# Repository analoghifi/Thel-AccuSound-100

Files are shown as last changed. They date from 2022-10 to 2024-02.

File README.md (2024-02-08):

# Thel AccuSound 100
Thel AccuSound 100 audio power amplifier module (mono single channel)  
using vertical MOSFETs (often generalised as "[HEXFET](https://sound-au.com/articles/hexfet.htm)s")
* RMS power output from 20W up to 500W\* (1000W\*\*) | 7Hz...1,5MHz [-3dB]  |  0,4µs
* Class-A-Mode possible | Bridge Mode possible  
* unbalanced (single-ended/asymmetrical) audio input  
* not DC-coupled (has an input Cap (KP film/foil))  
* using vertical MOSFETs IRFP240 / IRFP9240  
* integrated (DC-) protection & anti-pop delay -circuit with relays
  
\*(depends on the supply voltage only)  
\*\*(bridge mode and short time only ➔ see <a href="/docs/4.) final version 2003-2015/power_output_table_version_2003-2015.png">Table 1</a> / <a href="/docs/3) version 1995-2003/power_output_table_version_1995-2003__V2.jpg">Table 2</a>)  
  
#### changes from "3) version 1995-2003" *[AccuSound Pro]* to "4) final version 2003-2015" *[AccuSound 100]*:  
* introducing source resistors (for better stability / better thermal behaviour / better currenct and load sharing)
* therefore reduced power output (compare <a href="/docs/3) version 1995-2003/power_output_table_version_1995-2003__V2.jpg">old</a> with <a href="/docs/4.) final version 2003-2015/power_output_table_version_2003-2015.png">new</a>)
* slightly different schematic (compare <a href="/hardware/3) version 1995-2003/accusound_version_1995-2003_schematic_V1.jpg">old</a> with <a href="/hardware/4.) final version 2003-2015/AccuSound_100_schematic_2004__corrected.jpg">new</a>)
* different pcb layout
* in the middle of 2010: replacement of the 2 very good tungsten-silver double (two-step)\*\*\* contact relays (erosion-resistant) with 2 normal "high-current" relays (Schrack RP3SL024)  
* replacing almost all foil caps (including the input cap) with the very good CDE film/foil KP-caps (<a href="https://github.com/analoghifi/capacitors/blob/main/audio%20and%20filter%20capacitors/docs/datasheets/kp/CDE_series_WPP.pdf">WPP-Series</a>)
* introducing silver mica bypass caps at some sensible places in the circuit
  
\*\*\*(see here -> <a href="/docs/components datasheets/special relay version 1995-2003">Relay type: Hengstler H-550-1759"</a>)
  
.
  
## last 4.x) version sold from 2003 til 2015:  
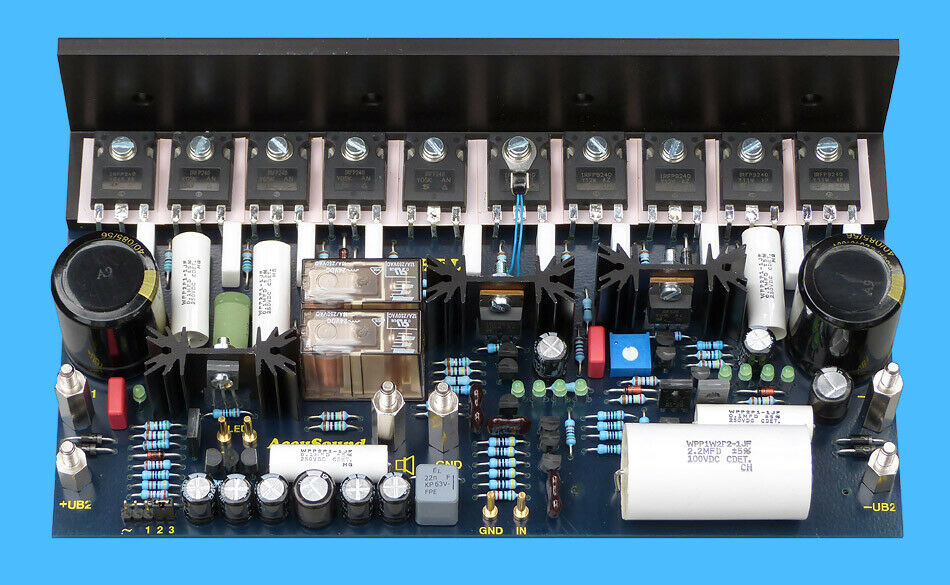
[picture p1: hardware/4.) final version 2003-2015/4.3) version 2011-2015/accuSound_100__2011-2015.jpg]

  
https://web.archive.org/web/20071014012558/http://www.thel-audioworld.de/module/acuso/acuso.htm  
https://web.archive.org/web/20120130132153/http://thel-audioworld.de/module/acuso/acuso.htm  
https://web.archive.org/web/20150216004915/http://www.thel-audioworld.de/module/acuso/acuso.htm  
  
## older 3) version sold from 1995 til 2003:  
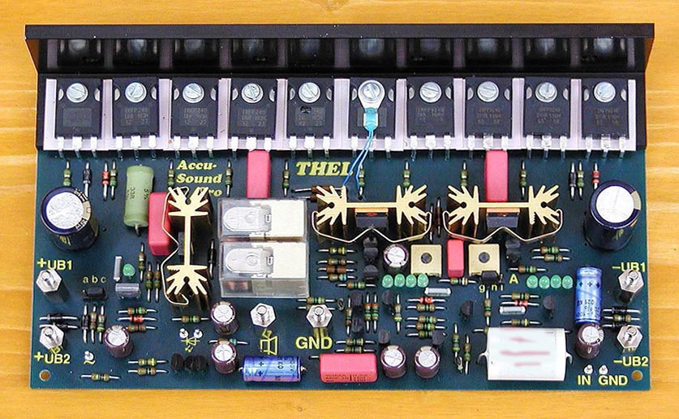
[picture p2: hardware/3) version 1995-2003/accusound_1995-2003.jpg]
  
  
https://web.archive.org/web/20020608091959/http://thel-audioworld.de:80/module/acuso/acuso.htm  

----  
### Kicad projects in this repo:  
* [version 2006-2011](https://github.com/analoghifi/Thel-AccuSound-100/tree/main/hardware/4.\)%20final%20version%202003-2015/4.2\)%20version%202006-2011/KiCad/original) | state: initial release v1.01 | like the original, 1-layer, THT
* [version 2011-2015](https://github.com/analoghifi/Thel-AccuSound-100/tree/main/hardware/4.\)%20final%20version%202003-2015/4.3\)%20version%202011-2015/KiCad/original) | state: coming soon... | like the original, 1-layer, THT

----

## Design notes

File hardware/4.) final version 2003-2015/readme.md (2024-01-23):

Accusound 100 = with normal 1% (metal film) resistors  
Accusound 10**1** = \"with low noise non-magnetic TKD-resistors 0.5% TCR:25ppm\" (until 2005: \"with low noise Welwyn-resistors 0.1% TCR:15ppm\")  
### Changes over the years:  
**4.1)** initial version (using the black Mundorf \"MCap audiophile\" KP caps [100V])
  
**4.2.1)** in 2006:
* small layout change on the PCB to give space for the new better KP (film/foil) input cap (CDE <a href="https://github.com/analoghifi/capacitors/blob/main/audio%20and%20filter%20capacitors/docs/datasheets/kp/CDE_series_WPP.pdf">WPP-Series</a>) paralleled with a small silver mica cap.  
* the two small holes at the bottom of the PCB disappeared  
* using the 2mm gold-plated (lathe made) brass solder pins (<a href="https://github.com/analoghifi/Thel-AccuSound-100/blob/main/docs/components%20datasheets/staeubli_42.0062_brass_pin_2mm__DE_EN_FR.pdf">Stäubli 42.0062</a>)
  
**4.2.2)** in the middle of 2010: replacement of the 2 very good <a href="/docs/components datasheets/special relay version 1995-2003">tungsten-silver double (two-step) contact relays</a> (erosion-resistant) with 2 normal "high-current" relays (<a href="https://github.com/analoghifi/Thel-AccuSound-100/blob/main/docs/components%20datasheets/relay_Schrack_RP3SL024.pdf">Schrack RP3SL024</a>)
  
**4.3)** in 2011 there was again a small layout change on the PCB to give the input capacitor even more space (compare the pics in the lower right corner),  
with that change the (more expensive) Accusound 10**1** got a (larger dimensions) 3.3µF input capacitor as a 'bonus' (instead of the normal 2.2µF of the Accusound 100)  
(the schematic is still the same (as it was from 2003 on), as well as all the components)

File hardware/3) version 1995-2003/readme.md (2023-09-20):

this 3) version 1995-2003 was named and sold as *\"AccuScound Pro\"*  
or later as *\"AccuScound Pro 100\"* & *\"AccuScound Pro 101\"*  
  
normal Version: *Accusound pro 100* = with normal 1% (metal film) resistors  
more expensive version: *Accusound pro 101* = \"with low noise Welwyn-resistors 0.1% TCR:15ppm\" (later: \"with low noise non-magnetic TKD-resistors 0.5% TCR:25ppm\")  
  
Input capacitor:  
either the white Mundorf \"MCap audiophile\" **M**KP caps [250V or 400V] *(on AccuScound pro 100)*  
or the (better) black Mundorf \"MCap audiophile\" KP caps [100V] *(on AccuScound pro 101)*  
  
Special [relay Version](https://github.com/analoghifi/Thel-AccuSound-100/tree/main/docs/components%20datasheets/special%20relay%20version%201995-2003) with "double contact"   
  


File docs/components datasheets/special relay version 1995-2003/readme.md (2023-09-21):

### Special relay Version with "double contact":  
In the AccuSound [version from 1995 to 2003](https://github.com/analoghifi/Thel-AccuSound-100/tree/main/hardware/3%29%20version%201995-2003) (and also in the "final <a href="https://github.com/analoghifi/Thel-AccuSound-100/tree/main/hardware/4.)%20final%20version%202003-2015">version 2003-2015</a>" until the middle of the year 2010)  
Thel uses a special relay type where the contact is designed as a double contact – a standard (AgSnO) contact and a [tungsten](https://en.wikipedia.org/wiki/Tungsten) (german: "Wolfram") leading contact ("pre-make contact").  
  
The tungsten leading contact closes earlier than the standard (AgSnO) contact when it is switched on. The latter is spared from the switch-on peaks. Only the lower continuous current flows through the standard (AgSnO) contact.  
At the moment of switch-off, the tungsten leading contact opens correspondingly later and thus keeps switch-off peaks (and sparks) away from the standard contact.  
(thus the standard (AgSnO) contact is always protected when switching on and off)  
  
Originally Thel used a [Hengstler H-550-1759](https://github.com/analoghifi/Thel-AccuSound-100/tree/main/docs/components%20datasheets/special%20relay%20version%201995-2003/Original%3A%20Hengstler%20H-550) relay  
alternatively you may use [Weidmueller RCLS3T024(W)](https://github.com/analoghifi/Thel-AccuSound-100/tree/main/docs/components%20datasheets/special%20relay%20version%201995-2003/Alternative%3A%20Weidmueller%20RCLS3T02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) if you want this "double contact"-feature (although the Weidmüller type was never used by Thel)  

----  
   
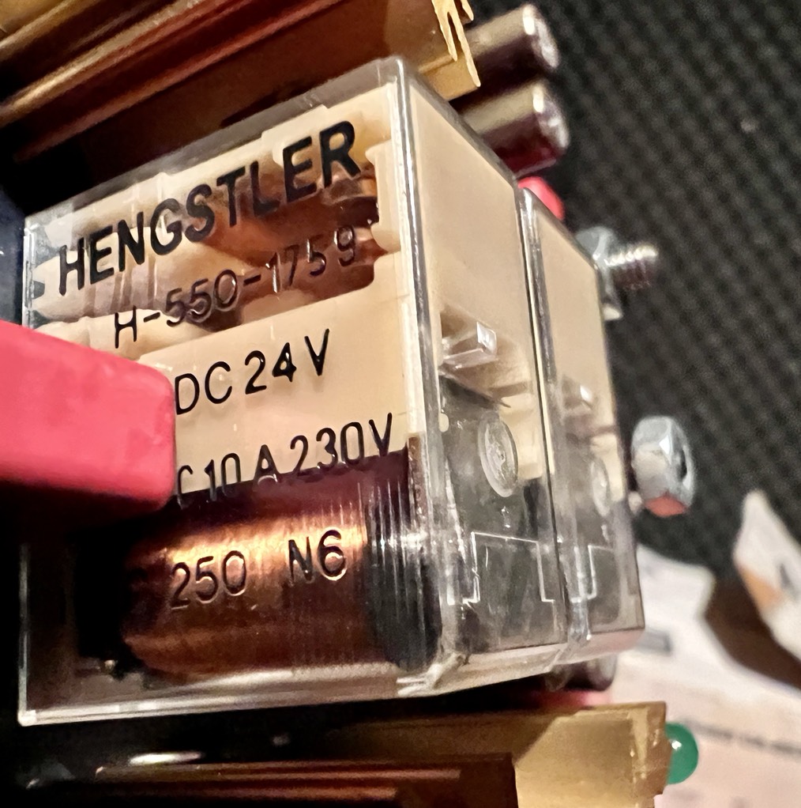
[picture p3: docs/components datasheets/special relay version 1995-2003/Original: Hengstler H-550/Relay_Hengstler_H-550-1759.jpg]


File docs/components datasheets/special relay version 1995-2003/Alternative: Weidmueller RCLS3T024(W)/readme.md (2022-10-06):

### Relay type: Weidmüller \"RCL Inrush Power\":  
In the \"RCL Inrush\" version, the relays offer a NO contact (AgSnO) with a nominal current of 16 A and have a making capacity of 120 A for 20 ms.  
In the **\"RCL Inrush Power\"** version, the contact is designed as a double contact – a standard (AgSnO) contact and a tungsten leading contact ("pre-make contact").

The tungsten leading contact closes earlier than the standard (AgSnO) contact when it is switched on. The latter is spared from the switch-on peaks. Only the lower continuous current flows through the standard (AgSnO) contact. At the moment of switch-off, the tungsten leading contact opens correspondingly later and thus keeps switch-off peaks away from the standard contact.

Tungsten, the contact material of the pre-make contact, absorbs inrush currents with capacitive loads of 165 A for 20 ms.  
The capacitive inrush peaks can be 800 A/200 µs. With inductive loads, the tungsten contact absorbs high breaking currents.  
  
➔ https://www-elektronikpraxis-de.translate.goog/aggressive-induktive-und-kapazitive-lasten-schalten-a-62116/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  
  
➔ https://www-pressebox-de.translate.goog/pressemitteilung/weidmueller/Weidmueller-Relais-RCL-Inrush-und-RCL-Inrush-Power-mit-voreilendem-Kontakt-aus-Wolfram/boxid/679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

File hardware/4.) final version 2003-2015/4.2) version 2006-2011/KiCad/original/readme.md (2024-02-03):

#### work in progress not finished yet !  

this is not the original Thel PCB but it's very like\* the original with the following exceptions:  
* different board dimensions original: 200mm x 100mm -> this PCB: 200mm x 103mm  
* using a combined 5.0mm/7.5mm pin spacing footprint for the small foil caps C12 and C23
* using a combined 3.5mm/5.0mm/5.9mm/7.5mm pin spacing footprint for the Mica caps C2, C3 and C9 (see below)  
  
\*(same schematic / same 1-layer\** layout THT / same THT components in the same places on the board)  
\**(strictly speaking, this KiCad PCB is a two-layer PCB with plated-through holes, but you can also (let) produce it as a classic 1-layer PCB with non-plated holes if you wish, since all the tracks are on the bottom side only)  
  
----  

### remarks:  
#### C2,C3,C9: 
in the original, Mica capacitors from the US company "Cornell Dubilier Electronics" (CDE) are used for C2, C3 and C9  
the [CD15-Series](https://github.com/analoghifi/capacitors/blob/main/audio%20and%20filter%20capacitors/docs/datasheets/mica%20glimmer/CDE_Silver_Mica_series_STD-DIPPED.pdf) or the better [CD17 Series](https://github.com/analoghifi/capacitors/blob/main/audio%20and%20filter%20capacitors/docs/datasheets/mica%20glimmer/CDE_Series_CD17_CD18_high_frequency.pdf) is used:  
* C2, C3 = 47pF / 1% / 500V / 5.9mm pitch / Type-No. CD15ED470FO3 ([stock at Mouser](https://www2.mouser.com/ProductDetail/Cornell-Dubilier-CDE/CD15ED470FO3?qs=9iVfQKk8ifFmXLRqX5bCNQ%3D%3D))  
or better CD17ED470JO3F ([stock at Mouser](https://www2.mouser.com/ProductDetail/Cornell-Dubilier-CDE/CD17ED470JO3F?qs=nnhpPVbCybXjnSWSlsUlRA%3D%3D))
* C9 = 10pF / 5% / 500V / 5.9mm pitch / Type-No. CD15CD100JO3 ([stock at Mouser](https://www2.mouser.com/ProductDetail/Cornell-Dubilier-CDE/CD15CD100JO3?qs=m9iv7GyUMnFXRIC2%252BbnrrQ%3D%3D))  
or better CD17CD100JO3F ([stock at Mouser](https://www2.mouser.com/ProductDetail/Cornell-Dubilier-CDE/CD17CD100JO3F?qs=PXF%252Blbo4VJ7Sv5GDGZWsoQ%3D%3D))

Alternatively:  
since C2,C3 and C9 are used for controlling the ultrasonic frequencies (>20kHz) here in this circuit you may use instead  
ceramic C0G capacitors (tolerance: 1% to 2,5% / rated DC Voltage: 100V or 250V / pitch 5mm or 7,5mm)  
e.g. KEMET "[goldmax 300](https://github.com/analoghifi/capacitors/blob/main/audio%20and%20filter%20capacitors/docs/datasheets/C0G/KEMET_C1049_GOLDMAX_C0G_THT.pdf)" Series in THT version ([10pF/47pF stock at mouser](https://www2.mouser.com/c/passive-components/capacitors/ceramic-capacitors/mlccs-multilayer-ceramic-capacitors/multilayer-ceramic-capacitors-mlcc-leaded/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))  
They perform very well for high frequencies and are a very good alternative to the expensive Mica caps from CDE.  
The dielectric material is important here: Do NOT use ceramic capacitors with a dielectric other than C0G (NP0) !  
  
The footprint on my PCB is prepared for both pitches:  
the odd 5.9mm for the Micas as well as 3.5mm / 5.0mm or 7.5mm for alternative capacitors  
 
----  
  
these are KiCad 6.x projects  
see how to get the proper 3D-Models from here: https://github.com/analoghifi/KiCad-3D-Models  
  
----  
  
use kicanvas.org to see this KiCad-Project in Browser:  
https://kicanvas.org/?github=https://github.com/analoghifi/Thel-AccuSound-100/tree/main/hardware/4.)%20final%20version%202003-2015/4.2)%20version%202006-2011/KiCad/original

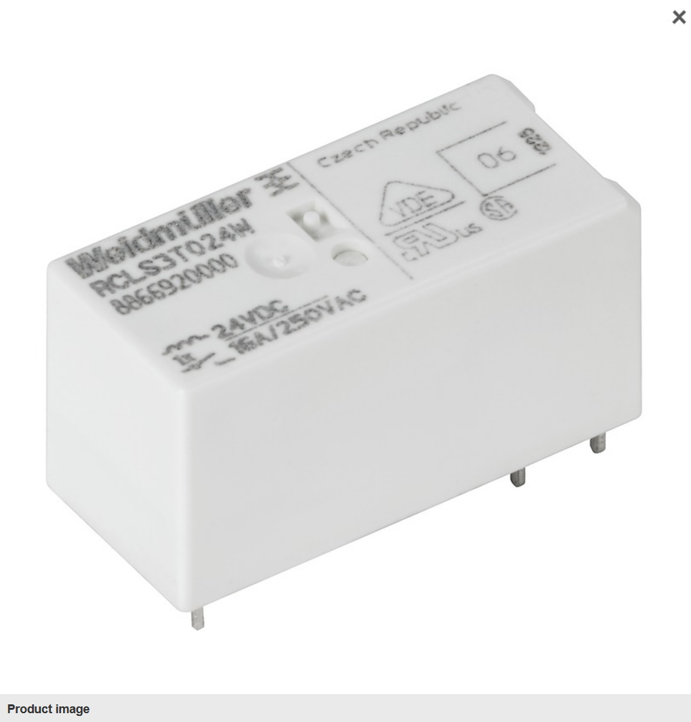
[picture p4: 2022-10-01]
docs/components datasheets/special relay version 1995-2003/Alternative: Weidmueller RCLS3T024(W)/Weidmueller_RCLS3T024(W)/Product_Image.jpg

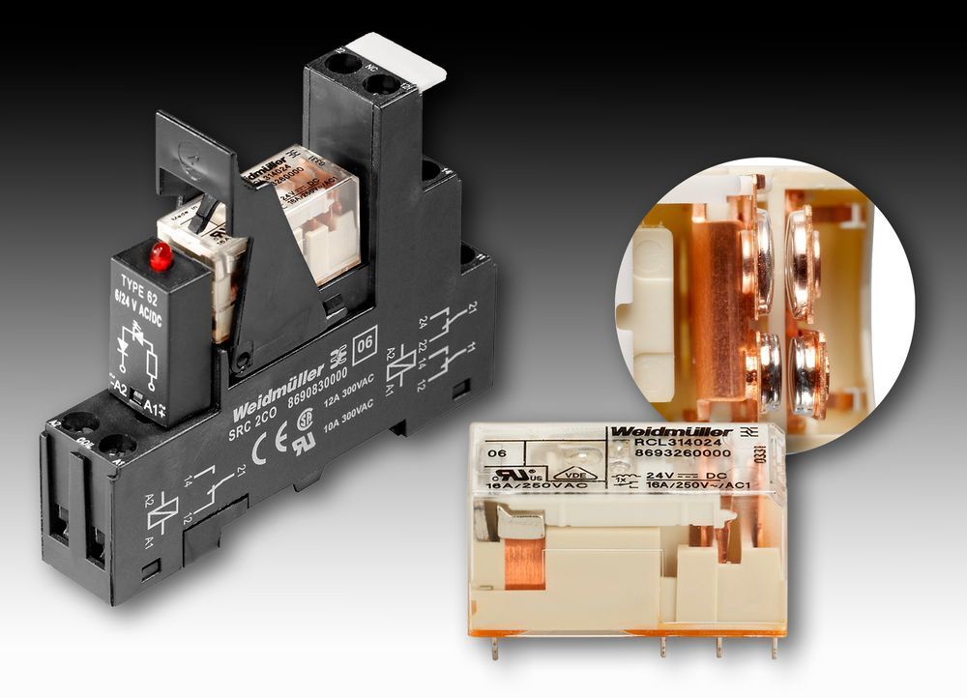
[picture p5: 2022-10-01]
docs/components datasheets/special relay version 1995-2003/Alternative: Weidmueller RCLS3T024(W)/press-photo.jpg

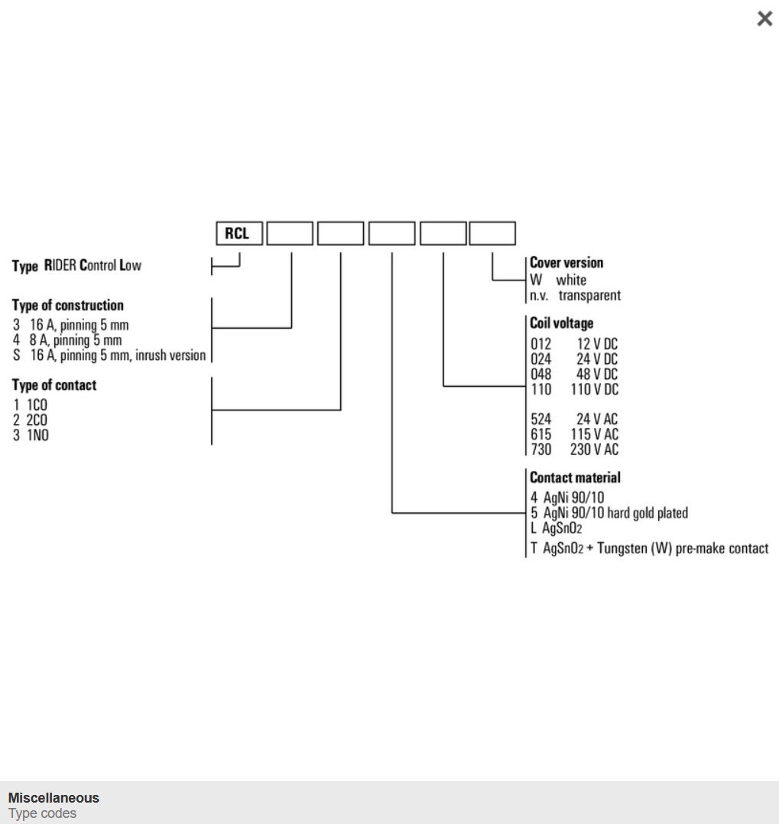
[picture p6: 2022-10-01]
docs/components datasheets/special relay version 1995-2003/Alternative: Weidmueller RCLS3T024(W)/Weidmueller_RCLS3T024(W)/Type_Codes.jpg

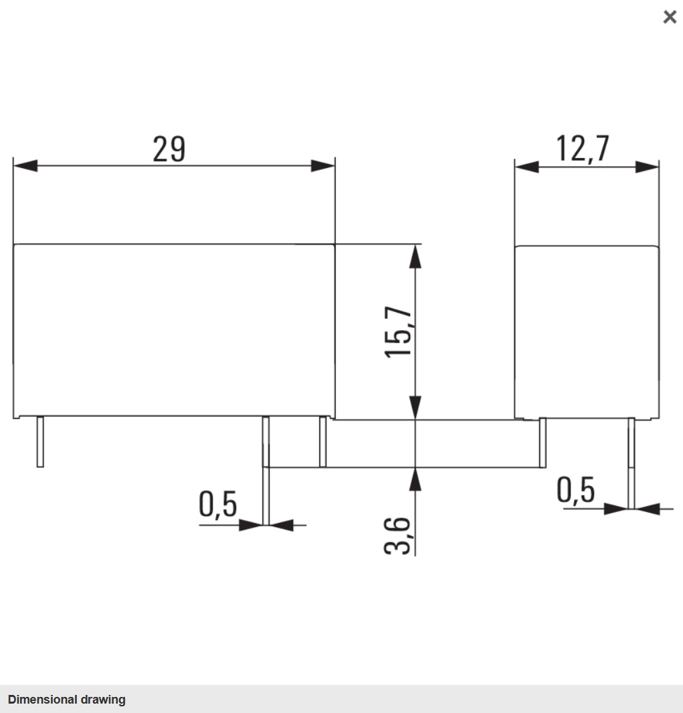
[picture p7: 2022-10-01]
docs/components datasheets/special relay version 1995-2003/Alternative: Weidmueller RCLS3T024(W)/Weidmueller_RCLS3T024(W)/Dimensional_Drawing.jpg

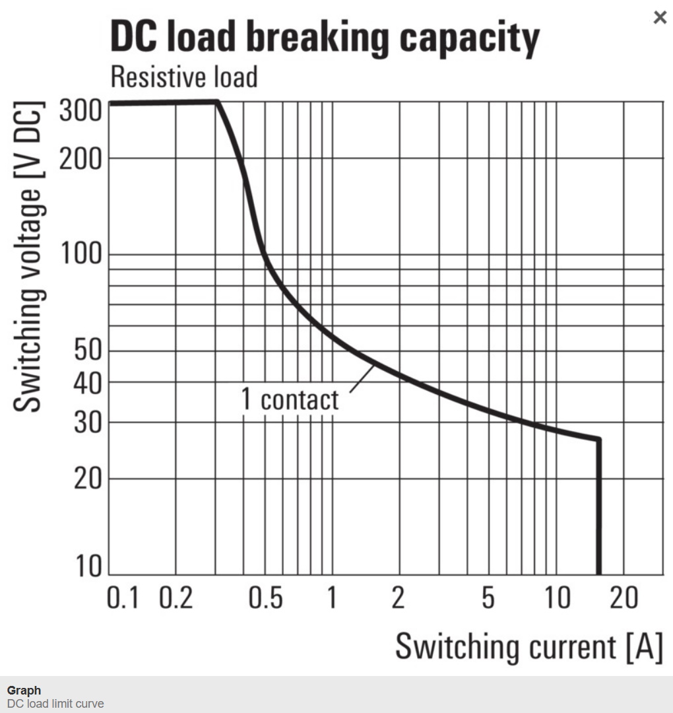
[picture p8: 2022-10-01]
docs/components datasheets/special relay version 1995-2003/Alternative: Weidmueller RCLS3T024(W)/Weidmueller_RCLS3T024(W)/DC_Load_Breaking_Capacity.jpg

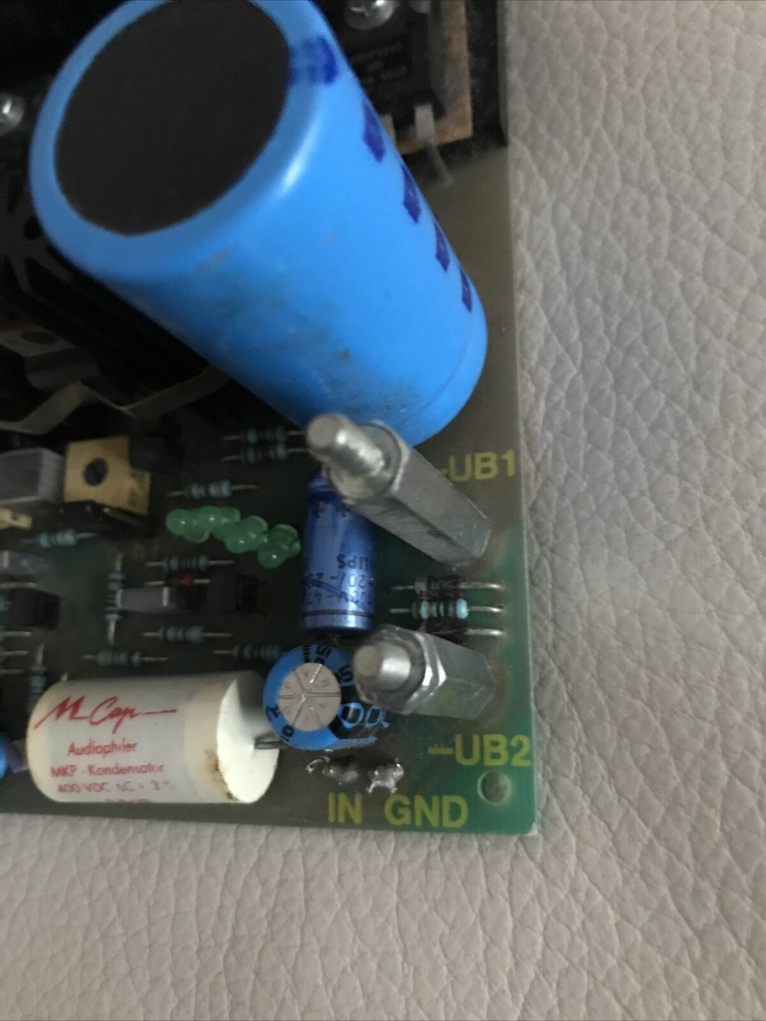
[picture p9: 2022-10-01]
hardware/3) version 1995-2003/accousound_100_5.jpg

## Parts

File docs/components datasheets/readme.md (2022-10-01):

Replacement parts:  
2SC2240 -> 2SC2713 (SMD) [toshiba] https://octopart.com/search?q=2SC2713  
2SC2240 -> KSC1845 [onsemi] https://octopart.com/search?q=KSC1845    
  
2SA970 -> 2SA1163 (SMD) [toshiba] https://octopart.com/search?q=2SA1163  
2SA970 -> KSA992 [onsemi] https://octopart.com/search?q=KSA992     
  
BF469 (NPN) -> 2SA1381 / KSA 1381 ?  
BF469 (NPN) -> BF720T1G (SMD) -> PZTA42T1G ?    
BF470 (PNP) -> 2SC3503 / KSC3503 ?  
BF470 (PNP) -> BF721T1G (SMD) -> PZTA92T1G ?

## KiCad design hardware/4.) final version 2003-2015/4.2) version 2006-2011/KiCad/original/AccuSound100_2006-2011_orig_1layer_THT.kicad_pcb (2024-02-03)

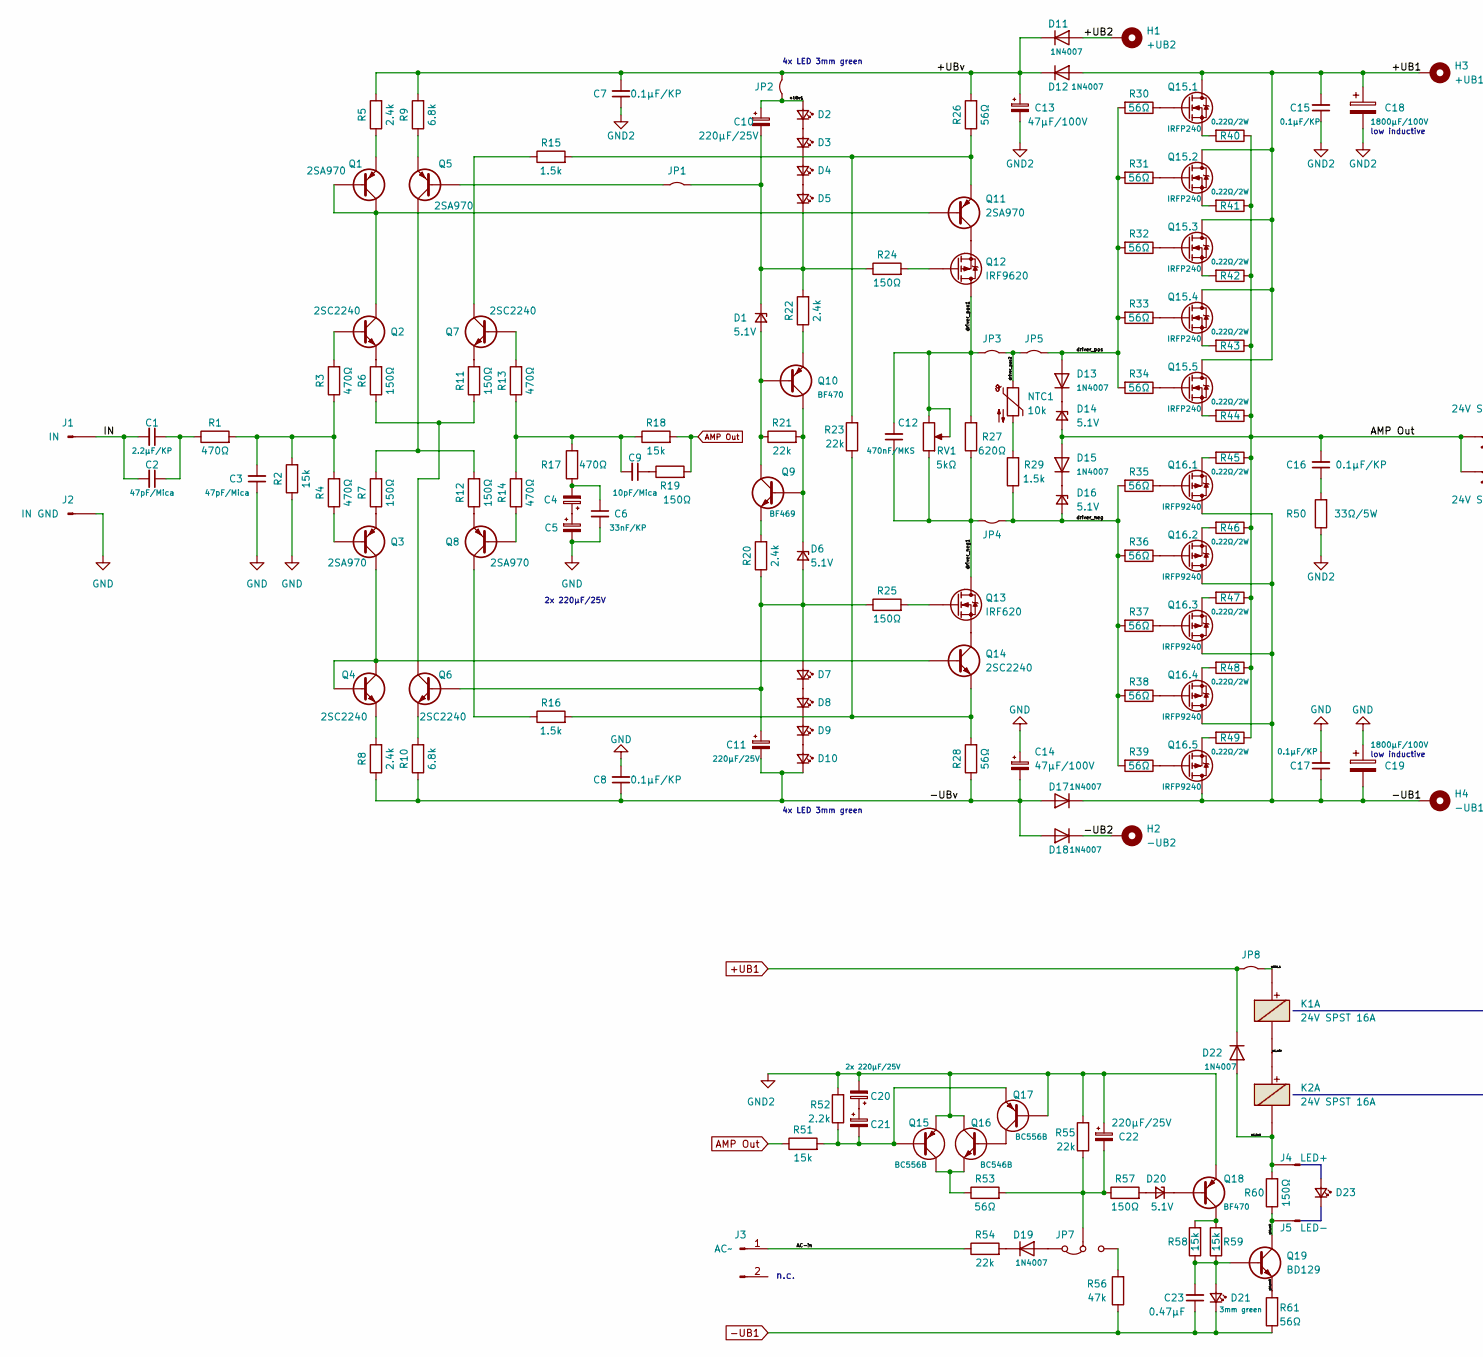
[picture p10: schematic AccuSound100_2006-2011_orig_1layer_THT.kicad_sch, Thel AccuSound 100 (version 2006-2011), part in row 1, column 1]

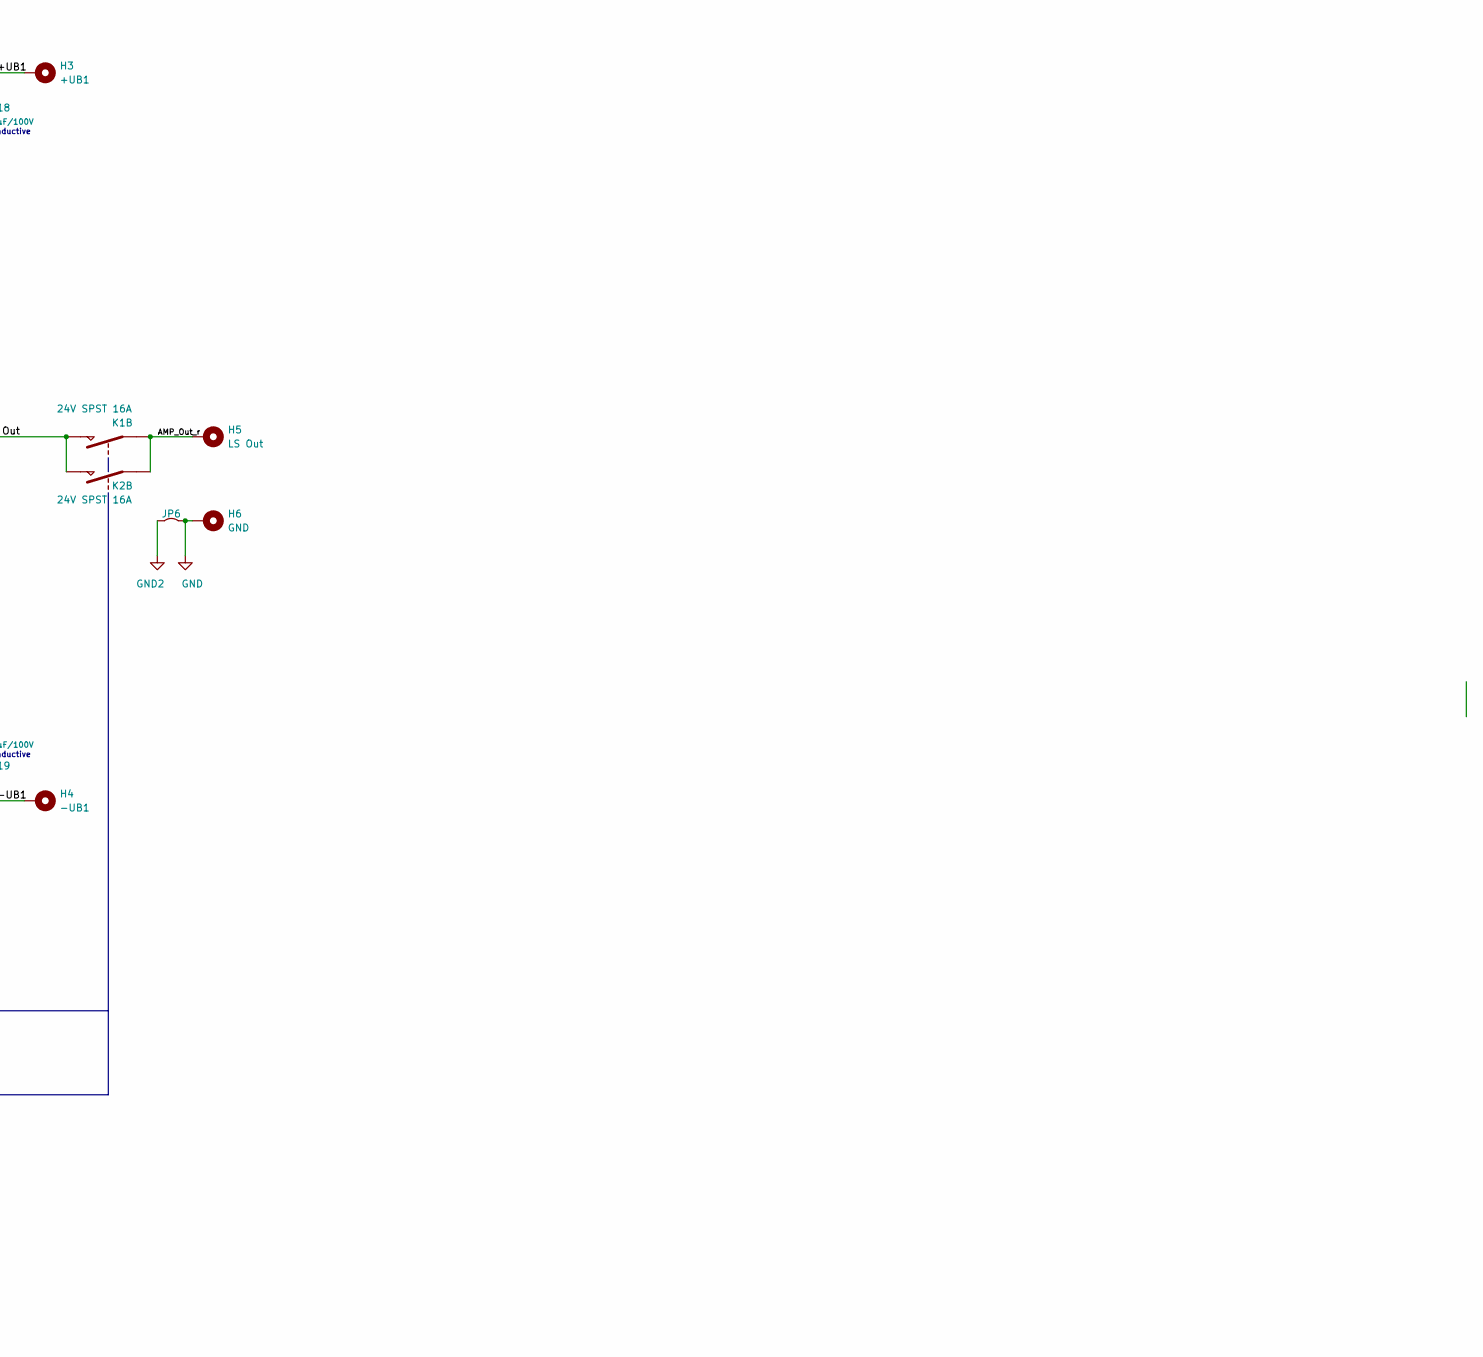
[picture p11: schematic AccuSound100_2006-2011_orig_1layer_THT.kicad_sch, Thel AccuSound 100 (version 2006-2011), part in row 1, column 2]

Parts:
C1: 2.2µF/KP; C_Axial_L42mm_D22mm_P45mm_Horizontal
C2, C3: 47pF/Mica; C_Rect_Mica_Multi_L11.0mm_W3.5mm_P3.50_P5.00_P5.90_P7.50mm
C4, C5, C10, C11, C21, C22: 220µF/25V; CP_Radial_Black_D8.2mm_H12.0mm_P3.50mm_minimal_silk
C6: 33nF/KP; C_Tower_EMZ_small_medium
C7, C8, C15, C16, C17: 0.1µF/KP; C_Axial_L27mm_D9mm_P27.5mm_Horizontal
C9: 10pF/Mica; C_Rect_Mica_Multi_L11.0mm_W3.5mm_P3.50_P5.00_P5.90_P7.50mm
C12: 470nF/MKS; C_Rect_L10.0mm_W4.0mm_P5.00_P7.50mm
C13, C14: 47µF/100V; CP_Radial_D10.0mm_H12.5mm_P5.00mm_minmal_silk
C18, C19: 1800µF/100V; CP_Radial_D26.0mm_P10.00mm_SnapIn
C20: 2x 220µF/25V; CP_Radial_Black_D8.2mm_H12.0mm_P3.50mm_minimal_silk
C23: 0.47µF; C_Rect_L10.0mm_W4.0mm_P5.00_P7.50mm
D1, D6, D20: 5.1V; D_DO-41_SOD81_very_long_P12.7mm_Horizontal_minSilk
D2, D5, D7, D8, D10, D23: LED_Small; LED_D3.0mm
D3, D4, D9: LED_Small; LED_D3.0mm_medium_P3.5mm
D11, D12: 1N4007; Diode_long_L6.3mm_D2.5mm_P11,43mm_Horizontal_minSilk
D13: 1N4007; Diode_L6.3mm_D2.5mm_P10.16mm_Horizontal_minSilk
D14: 5.1V; D_DO-41_SOD81_short_P9.0mm_Horiz_minSilk
D15: 1N4007; Diode_short_L6.3mm_D2.5mm_P9mm_Horizontal_minSilk
D16: 5.1V; D_DO-41_SOD81_P10.16mm_Horizontal_minSilk
D17, D18, D19: 1N4007; Diode_long_L6.3mm_D2.5mm_P12.7mm_Horizontal_minSilk
D21: 3mm green; LED_D3.0mm
D22: 1N4007; D_DO-41_SOD81_very_short_P7.62mm_Horiz_minSilk
H1: +UB2; MountingHole_4.3mm_M4_big_Pad_TopBottom
H2: -UB2; MountingHole_4.3mm_M4_big_Pad_TopBottom
H3: +UB1; MountingHole_4.3mm_M4_big_Pad_TopBottom
H4: -UB1; MountingHole_4.3mm_M4_big_Pad_TopBottom
H5: LS Out; MountingHole_4.3mm_M4_big_Pad_TopBottom
H6: GND; MountingHole_4.3mm_M4_big_Pad_TopBottom
J1: IN; Loet_Pin_D1.5mm_L14.0mm
J2: IN GND; Loet_Pin_D1.5mm_L14.0mm
J3: AC~; PinHeader_1x02_P2.54mm_Vertical
J4: LED+; Loet_Pin_D1.5mm_L14.0mm
J5: LED-; Loet_Pin_D1.5mm_L14.0mm
JP1, JP3: Jumper_2_Bridged; R_Axial_long_L6.3mm_D2.5mm_P11.43mm_Horizontal_minSilk
JP2, JP4, JP8: Jumper_2_Bridged; R_Axial_very_long_L6.3mm_D2.5mm_P12.7mm_Horizontal_minSilk
JP5: Jumper_2_Bridged; R_Axial_even_longer_L6.3mm_D2.5mm_P13.2mm_Horizontal_minSilk
JP6: Jumper_2_Bridged; bridge_Wire-1.5mm_diameter
JP7: Jumper_3_Bridged12; PinHeader_1x03_P2.54mm_Vertical
K1, K2: 24V SPST 16A; Relay_SPST_Schrack-RM5mm
NTC1: 10k; Pads_for_NTC_P3mm
Q1, Q8: 2SA970; TO-92
Q2, Q4, Q7: 2SC2240; TO-92
Q3, Q5: 2SA970; TO-92_wide
Q6, Q14: 2SC2240; TO-92_wide
Q9: BF469; TO-126-3_Vertical
Q10, Q18: BF470; TO-126-3_Vertical
Q11: 2SA970; TO-92_Wide
Q12: IRF9620; TO-220-3_Vertical
Q13: IRF620; TO-220-3_Vertical
Q15, Q17: BC556B; TO-92_wide
Q15.1, Q15.2, Q15.3, Q15.4, Q15.5: IRFP240; TO-247-3_Horizontal_TabDown_short
Q16: BC546B; TO-92_wide
Q16.1, Q16.2, Q16.3, Q16.4, Q16.5: IRFP9240; TO-247-3_Horizontal_TabDown_short
Q19: BD129; TO-126-3_Vertical
R1, R3, R4, R13, R14, R17: 470Ω; R_Axial_very_long_L6.3mm_D2.5mm_P12.7mm_Horizontal_minSilk
R2, R18, R51, R58, R59: 15k; R_Axial_very_long_L6.3mm_D2.5mm_P12.7mm_Horizontal_minSilk
R5, R8, R20, R22: 2.4k; R_Axial_very_long_L6.3mm_D2.5mm_P12.7mm_Horizontal_minSilk
R6, R7, R11, R12, R19, R25, R57, R60: 150Ω; R_Axial_very_long_L6.3mm_D2.5mm_P12.7mm_Horizontal_minSilk
R9, R10: 6.8k; R_Axial_very_long_L6.3mm_D2.5mm_P12.7mm_Horizontal_minSilk
R15, R29: 1.5k; R_Axial_very_long_L6.3mm_D2.5mm_P12.7mm_Horizontal_minSilk
R16: 1.5k; R_Axial_DIN0207_L6.3mm_D2.5mm_P10.16mm_Horizontal_minSilk
R21, R23, R54, R55: 22k; R_Axial_very_long_L6.3mm_D2.5mm_P12.7mm_Horizontal_minSilk
R24: 150Ω; R_Axial_DIN0207_L6.3mm_D2.5mm_P10.16mm_Horizontal_minSilk
R26, R28, R31, R32, R33, R34, R35, R36, R37, R38, R53, R61: 56Ω; R_Axial_very_long_L6.3mm_D2.5mm_P12.7mm_Horizontal_minSilk
R27: 620Ω; R_Axial_Short_L6.3mm_D2.5mm_P9.0mm_Horiz_minSilk
R30, R39: 56Ω; R_Axial_long_L6.3mm_D2.5mm_P11.43mm_Horizontal_minSilk
R40, R41, R42, R43, R44, R45, R46, R47, R48, R49: 0.22Ω/2W; R_Box_L13.0mm_W4.0mm_P9.00mm
R50: 33Ω/5W; R_Axial_DIN0918_L18mm_D9mm_P22mm_Horizontal
R52: 2.2k; R_Axial_very_long_L6.3mm_D2.5mm_P12.7mm_Horizontal_minSilk
R56: 47k; R_Axial_very_long_L6.3mm_D2.5mm_P12.7mm_Horizontal_minSilk
RV1: 5kΩ; Potentiometer_Bourns_3386P_Vertical

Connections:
+UB1: C15.2, C18.1, D12.2 (A), D22.1 (K), H3.1, JP8.1 (A), Q15.1.2 (D), Q15.2.2 (D), Q15.3.2 (D), Q15.4.2 (D), Q15.5.2 (D)
-UB1: C17.1, C19.2, C23.1, D17.1 (K), D21.1 (K), H4.1, Q16.1.2 (D), Q16.2.2 (D), Q16.3.2 (D), Q16.4.2 (D), Q16.5.2 (D), R56.1, R61.1
/+UB1_1: JP8.2 (B), K1.A1
/+UB2: D11.2 (A), H1.1
/+UBv: C7.2, C13.1, D11.1 (K), D12.1 (K), JP2.2 (B), R5.2, R9.2, R26.2
/+UBv1: C10.1, D2.2 (A), JP2.1 (A)
/-UB2: D18.1 (K), H2.1
/-UBv: C8.1, C11.2, C14.2, D10.1 (K), D17.2 (A), D18.2 (A), R8.1, R10.1, R28.1
/AC-in: J3.1, R54.1
/AMP_Out_r: H5.1, K1.11, K2.11
/IN: C1.2, C2.2, J1.1
/driver_neg: D16.2 (A), JP4.1 (A), R29.1, R35.2, R36.2, R37.2, R38.2, R39.2
/driver_neg1: C12.1, JP4.2 (B), Q13.2 (D), R27.1, RV1.1
/driver_pos: D13.2 (A), JP5.2 (B), R30.2, R31.2, R32.2, R33.2, R34.2
/driver_pos1: C12.2, JP3.1 (A), Q12.2 (D), R27.2, RV1.2, RV1.3
/driver_pos2: JP3.2 (B), JP5.1 (A), NTC1.1
/q19_coll: J5.1, Q19.2 (C), R60.1
/q19_emit: Q19.1 (E), R61.2
/rel_foot: D22.2 (A), J4.1, K2.A2, R60.2
/rel_mid: K1.A2, K2.A1
AMP Out: C16.2, D14.2 (A), D15.2 (A), K1.14, K2.14, R18.2, R19.2, R40.1, R41.1, R42.1, R43.1, R44.1, R45.1, R46.1, R47.1, R48.1, R49.1, R51.1
GND: C3.1, C5.2, C6.2, C8.2, C14.1, C17.2, C19.1, H6.1, J2.1, JP6.2 (B), R2.1
GND2: C7.1, C13.2, C15.1, C18.2, C20.2, C22.1, JP6.1 (A), Q15.3 (E), Q16.1 (C), Q17.2 (B), Q18.1 (E), R50.1, R52.2, R55.2
unnamed: C1.1, C2.1, R1.1
unnamed: C3.2, R1.2, R2.2, R3.1, R4.2
unnamed: C4.1, C5.1
unnamed: C4.2, C6.1, R17.1
unnamed: C9.1, R19.1
unnamed: C9.2, R13.1, R14.2, R17.2, R18.1
unnamed: C10.2, D1.1 (K), D5.1 (K), JP1.2 (B), R22.2, R24.1
unnamed: C11.1, D6.2 (A), D7.2 (A), Q6.3 (B), R20.1, R25.1
unnamed: C16.1, R50.2
unnamed: C20.1, C21.1
unnamed: C21.2, Q15.2 (B), Q17.3 (E), R51.2, R52.1
unnamed: C22.2, JP7.2 (C), R53.2, R55.1, R57.1
unnamed: C23.2, D21.2 (A), Q19.3 (B), R58.1, R59.1
unnamed: D1.2 (A), Q9.2 (C), Q10.3 (B), R21.1
unnamed: D2.1 (K), D3.2 (A)
unnamed: D3.1 (K), D4.2 (A)
unnamed: D4.1 (K), D5.2 (A)
unnamed: D6.1 (K), Q9.3 (B), Q10.2 (C), R21.2
unnamed: D7.1 (K), D8.2 (A)
unnamed: D8.1 (K), D9.2 (A)
unnamed: D9.1 (K), D10.2 (A)
unnamed: D13.1 (K), D14.1 (K)
unnamed: D15.1 (K), D16.1 (K)
unnamed: D19.1 (K), R54.2
unnamed: D19.2 (A), JP7.1 (A)
unnamed: D20.1 (K), Q18.3 (B)
unnamed: D20.2 (A), R57.2
unnamed: JP1.1 (A), Q5.3 (B)
unnamed: JP7.3 (B), R56.2
unnamed: NTC1.2, R29.2
unnamed: Q1.1 (E), R5.1
unnamed: Q1.2 (C), Q1.3 (B), Q2.2 (C), Q11.3 (B)
unnamed: Q2.1 (E), R6.2
unnamed: Q2.3 (B), R3.2
unnamed: Q3.1 (E), R7.1
unnamed: Q3.3 (B), R4.1
unnamed: Q4.1 (E), R8.2
unnamed: Q5.1 (E), R9.1
unnamed: Q5.2 (C), R7.2, R12.2
unnamed: Q6.1 (E), R10.2
unnamed: Q6.2 (C), R6.1, R11.1
unnamed: Q7.1 (E), R11.2
unnamed: Q7.2 (C), R15.1
unnamed: Q7.3 (B), R13.2
unnamed: Q8.1 (E), R12.1
unnamed: Q8.2 (C), R16.1
unnamed: Q8.3 (B), R14.1
unnamed: Q9.1 (E), R20.2
unnamed: Q10.1 (E), R22.1
unnamed: Q11.1 (E), R15.2, R23.2, R26.1
unnamed: Q11.2 (C), Q12.3 (S)
unnamed: Q12.1 (G), R24.2
unnamed: Q13.1 (G), R25.2
unnamed: Q13.3 (S), Q14.2 (C)
unnamed: Q14.1 (E), R16.2, R23.1, R28.2
unnamed: Q3.2 (C), Q4.2 (C), Q4.3 (B), Q14.3 (B)
unnamed: Q15.1 (C), Q16.3 (E), R53.1
unnamed: Q15.1.1 (G), R30.1
unnamed: Q15.1.3 (S), R40.2
unnamed: Q15.2.1 (G), R31.1
unnamed: Q15.2.3 (S), R41.2
unnamed: Q15.3.1 (G), R32.1
unnamed: Q15.3.3 (S), R42.2
unnamed: Q15.4.1 (G), R33.1
unnamed: Q15.4.3 (S), R43.2
unnamed: Q15.5.1 (G), R34.1
unnamed: Q15.5.3 (S), R44.2
unnamed: Q16.2 (B), Q17.1 (C)
unnamed: Q16.1.1 (G), R35.1
unnamed: Q16.1.3 (S), R45.2
unnamed: Q16.2.1 (G), R36.1
unnamed: Q16.2.3 (S), R46.2
unnamed: Q16.3.1 (G), R37.1
unnamed: Q16.3.3 (S), R47.2
unnamed: Q16.4.1 (G), R38.1
unnamed: Q16.4.3 (S), R48.2
unnamed: Q16.5.1 (G), R39.1
unnamed: Q16.5.3 (S), R49.2
unnamed: Q18.2 (C), R58.2, R59.2

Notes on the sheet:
4x LED 3mm green
n.c.
low inductive
2x 220µF/25V

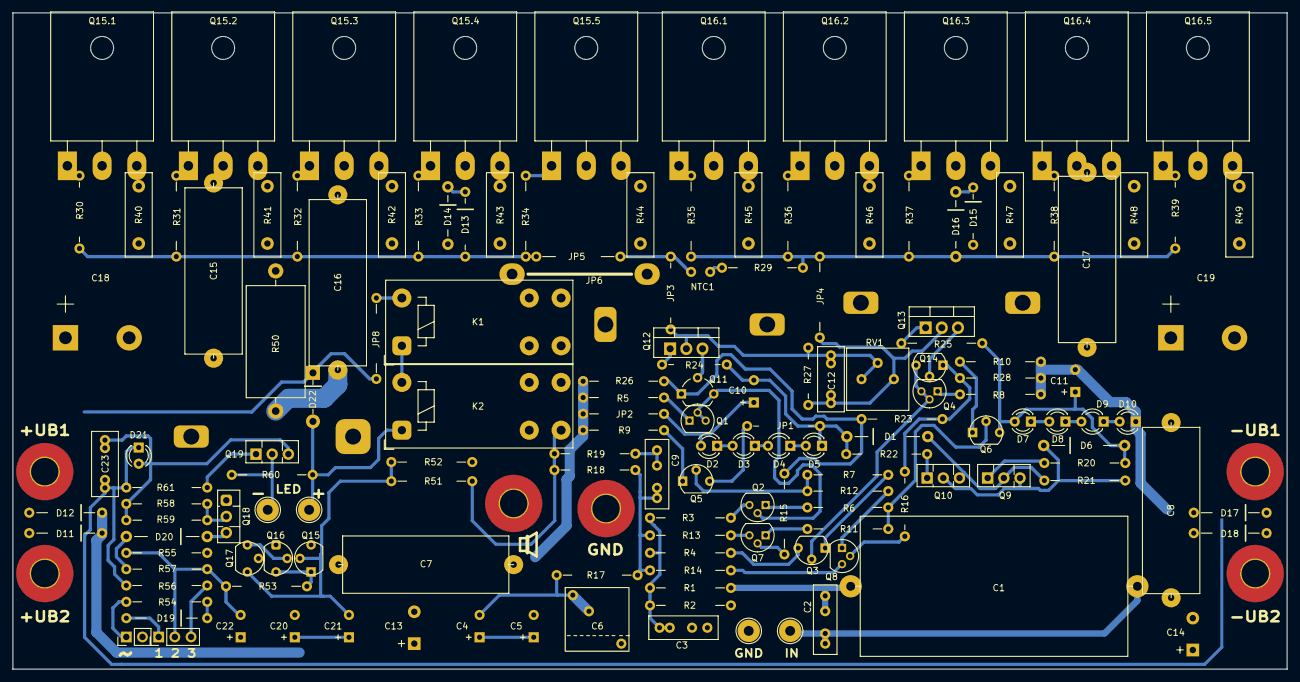
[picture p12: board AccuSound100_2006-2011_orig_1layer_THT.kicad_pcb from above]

Board: 2 copper layers, 200.0 x 103.0 mm, 158 parts (0 on the bottom side), 102 nets.
